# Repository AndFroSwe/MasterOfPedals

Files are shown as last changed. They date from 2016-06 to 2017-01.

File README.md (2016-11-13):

# Master of Pedals
A guitar pedal switching rig. Readymade presets are chosen by hitting a
footswitch on the stage pedal. The final goal of the repo is to have a modular
design that can easily be modified to the given specs.

# Features

1. At the hit of a footswitch, pedals are engaged as per the corresponding
   preset. No more tapdancing!
2. Presets can be changed on the main unit.

# Units

- __Control unit__: The main control unit. All pedals are connected to this and
presets are set here. 
- __Stage pedal__: Unit placed at the front of the stage. Has a set of
  footswitches for preset choice and a simple interface that shows the user
which preset is currently chosen.

# Repository guide

- __./Software/__ contains all source code for the MCUs. Divided into subfolders
  corresponding to the stage pedal and the control unit.
- __./KiCad/__ contains electrical schematics. Divided into subfolders
  corresponding to the stage pedal and the control unit.

# Prototype unit
The repo has a fully ready-to-go (when it's done) unit. This unit has the
following specs:

- 8 pedals in the control loop.
- 3 independently controlled amp channels.
- 6 presets.
- Stage pedal is connected via cord (i.e. it is not wireless).
- It has a simple user interface at the control unit that allows the user to
  change the presets.

# Future features
- __MIDI control output__: An output that can send MIDI messages to pedals.
- __Wireless control__: The stage pedal can send control signals to the control
  unit wirelessly. This also enables multiple control units. This could be used
in a mini control unit that is carried on the guitar.
- __Internal pedal power supply__: The control unit contains a PSU that can feed
  the guitar pedals with power.
- __Battery power supply__: The stage pedal runs on battery.
- __Data logging__: The pedal remembers which presets have been used.

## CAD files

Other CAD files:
KiCad/Channel switch prototype/Channel_Sw_Prototype-F.SilkS.dxf

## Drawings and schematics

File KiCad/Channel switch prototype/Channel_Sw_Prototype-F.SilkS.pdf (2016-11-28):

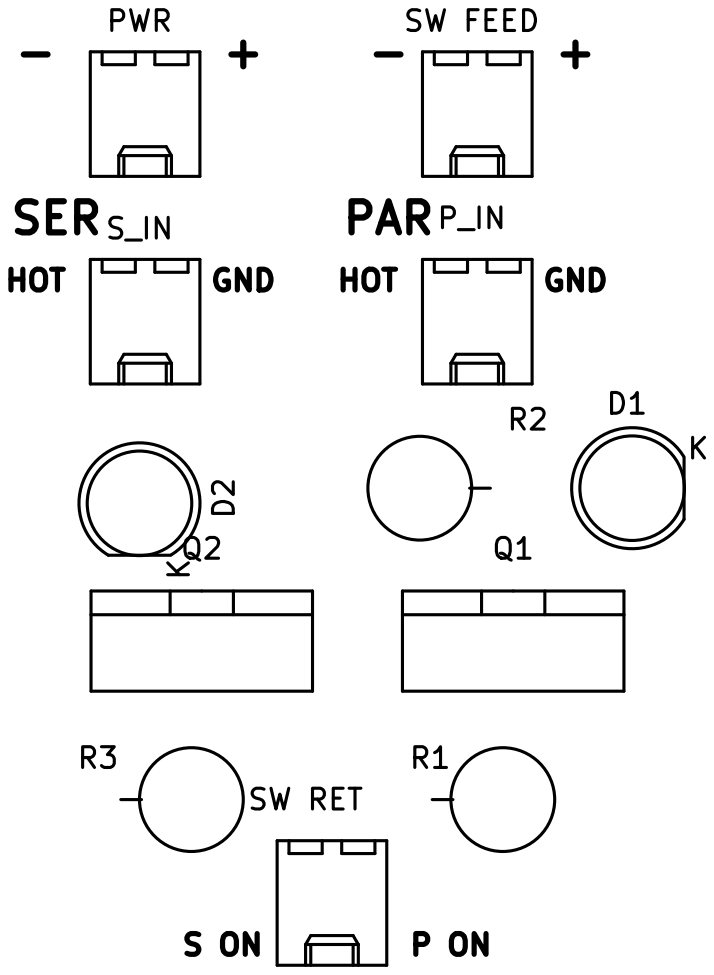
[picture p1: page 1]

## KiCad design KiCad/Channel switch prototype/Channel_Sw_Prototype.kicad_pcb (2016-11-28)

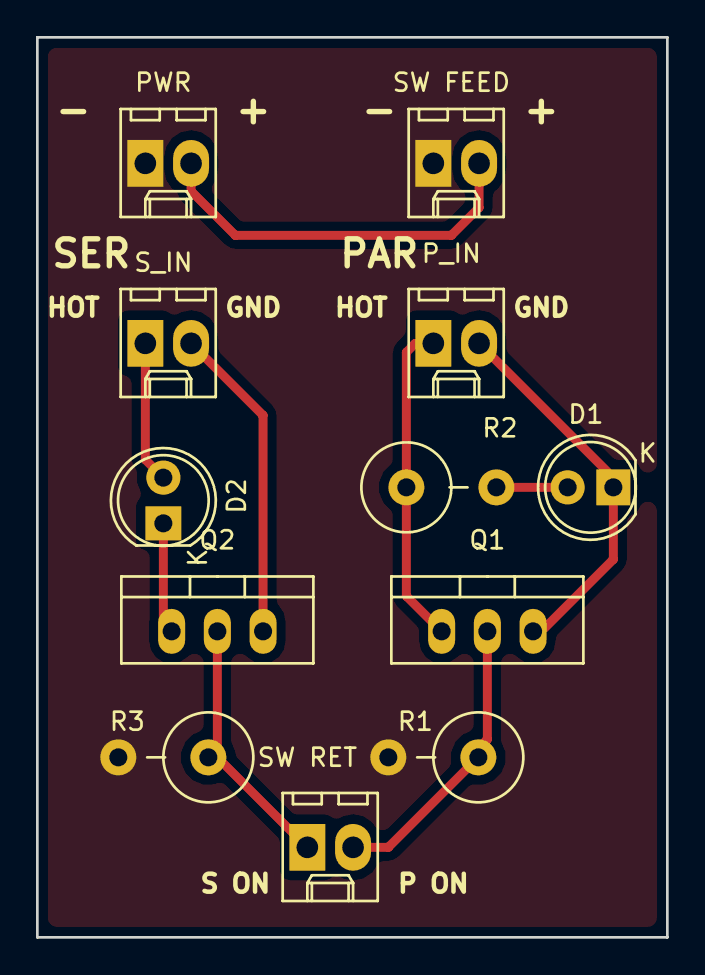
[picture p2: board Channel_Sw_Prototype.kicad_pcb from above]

Board: 2 copper layers, 35.0 x 50.0 mm, 12 parts (0 on the bottom side), 10 nets.

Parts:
D1, D2: LED; LED-5MM
PWR: PWR; Molex_KK-6410-02_02x2.54mm_Straight
P_IN: P IN; Molex_KK-6410-02_02x2.54mm_Straight
Q1, Q2: BUZ11; TO-220_Neutral123_Vertical
R1, R3: 1M; Resistor_Vertical_RM5mm
R2: 1.5k; Resistor_Vertical_RM5mm
SW FEED: SW FEED; Molex_KK-6410-02_02x2.54mm_Straight
SW RET: SW RETURN; Molex_KK-6410-02_02x2.54mm_Straight
S_IN: S IN; Molex_KK-6410-02_02x2.54mm_Straight

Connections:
/P_ON: Q1.2, R1.1, SW RET.2
/S_ON: Q2.2, R3.1, SW RET.1
/TELE_P_GND: D1.1, P_IN.2, Q1.3
/TELE_P_HOT: P_IN.1, Q1.1, R2.1
/TELE_S_GND: Q2.3, S_IN.2
/TELE_S_HOT: D2.2, S_IN.1
GND: PWR.1, R1.2, R3.2, SW FEED.1
unnamed: D1.2, R2.2
unnamed: D2.1, Q2.1
VCC: PWR.2, SW FEED.2

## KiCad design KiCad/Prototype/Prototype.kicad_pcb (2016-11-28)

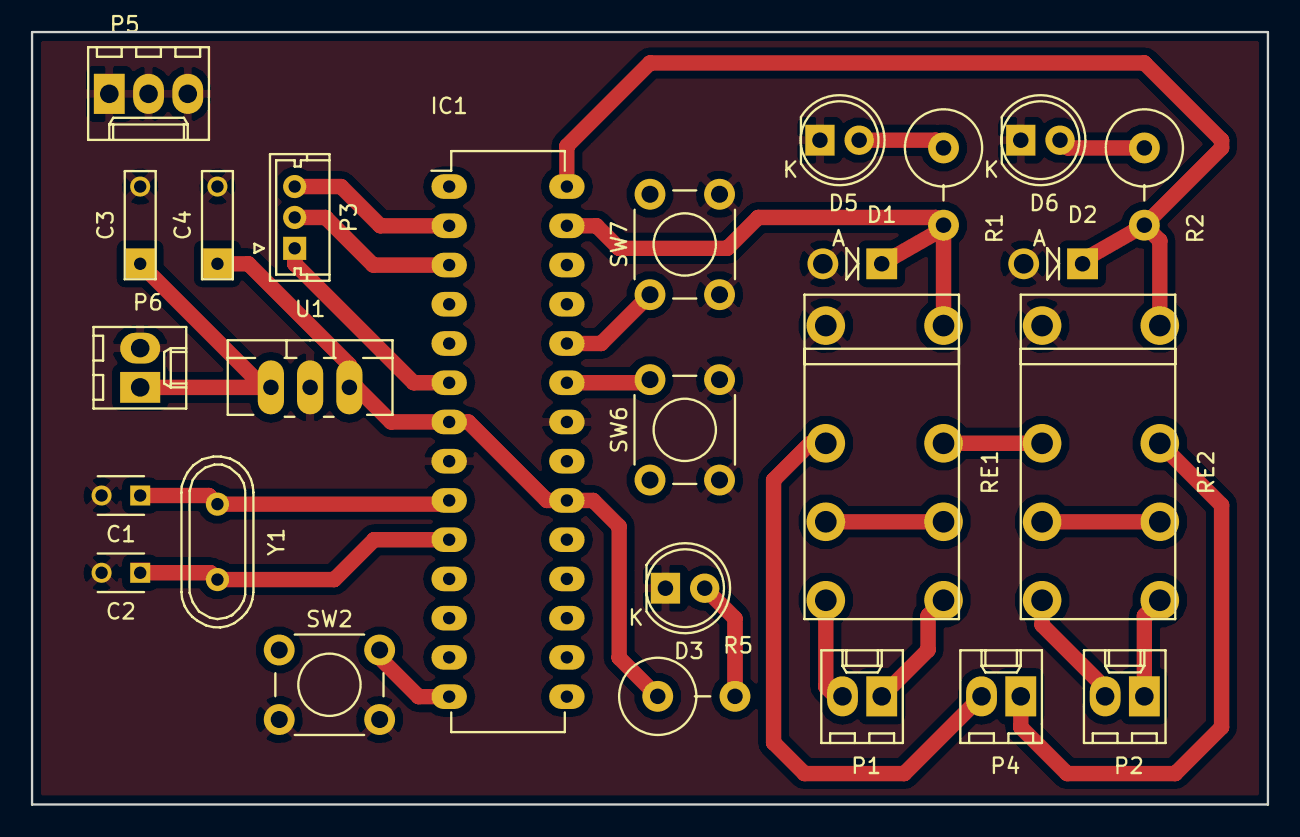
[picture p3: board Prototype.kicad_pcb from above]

Board: 2 copper layers, 80.0 x 50.0 mm, 26 parts (0 on the bottom side), 25 nets.

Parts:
C1, C2: 22pF; C_Disc_D3_P2.5
C3, C4: C; C_Rect_L7_W2_P5
D1, D2: D_Schottky; Diode_DO-41_SOD81_Vertical_AnodeUp
D3, D5, D6: LED; LED-5MM
IC1: ATMEGA328-P; DIP-28_W7.62mm_LongPads
P1, P2, P4, P6: CONN_01X02; Molex_KK-6410-02_02x2.54mm_Straight
P3: CONN_01X03; Molex_MicroLatch-53253-0370_03x2.00mm_Straight
P5: CONN_01X03; Molex_KK-6410-03_03x2.54mm_Straight
R1, R2, R5: R; Resistor_Vertical_RM5mm
RE1, RE2: DPDT-5V; DS2Y_PAK
SW2, SW6, SW7: SW_PUSH; SW_PUSH_6mm
U1: LM7805CT; TO-220_Neutral123_Vertical_LargePads
Y1: Crystal; Crystal_HC49-U_Vertical

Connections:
/G_IN: P4.2, RE1.7
/G_OUT: P4.1, RE2.2
/PED_1: D1.1, IC1.27, R1.2, RE1.1
/PED_2: D2.1, IC1.28, R2.2, RE2.1
/PRESET_1: IC1.14, SW2.1
/RX: IC1.2, P3.3
/SET_1: IC1.23, SW6.1
/SET_2: IC1.24, SW7.1
/TX: IC1.3, P3.2
/XCK: IC1.6, P3.1
/XTAL1: C1.1, IC1.9, Y1.1
/XTAL2: C2.1, IC1.10, Y1.2
GND: C1.2, C2.2, C3.2, C4.2, D1.2, D2.2, D3.1, D5.1, D6.1, IC1.8, IC1.22, P5.1, P5.2, P5.3, P6.2, RE1.8, RE2.8, SW2.2, SW6.2, SW7.2, U1.2
unnamed: D3.2, R5.2
unnamed: D5.2, R1.1
unnamed: D6.2, R2.1
unnamed: P1.1, RE1.4
unnamed: P1.2, RE1.5
unnamed: P2.1, RE2.4
unnamed: P2.2, RE2.5
unnamed: RE1.2, RE2.7
unnamed: RE1.3, RE1.6
unnamed: RE2.3, RE2.6
VCC: C3.1, P6.1, U1.1
VDD: C4.1, IC1.7, IC1.20, R5.1, U1.3

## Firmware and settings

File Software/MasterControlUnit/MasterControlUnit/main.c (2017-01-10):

/*
 * MasterControlUnit.c
 *
 * Created: 1/3/2017 5:01:10 PM
 * Author : Andreas Fröderberg
 */ 

#include "main.h"

/* Define states */
State s_run1 = {
	enc_green_on,
	enc_green_off
};

State s_run2 = {
	enc_red_on,
	enc_red_off
};

/* States and events */
State *states[] = {&s_run1,  &s_run2}; /* State array */
typedef enum State_code {run1, run2} State_code; /* State enumerators. Used for access */
typedef enum Event_code {enc_plus, enc_minus} Event_code; /* Available events */

typedef struct transitions { /* Standard transition format */
	State_code this_state;
	Event_code this_event;
	State_code next_state;
} Transitions;

Transitions transition_lookup[] = { /* Lookup table for all transitions */
	{run1, enc_plus, run2},
	{run1, enc_minus, run2},
	{run2, enc_plus, run1}
};

#define TRANS_COUNT (sizeof(transition_lookup)/sizeof(*transition_lookup)) /* Define number of transitions */

State_code cur_state = run1;

int main(void)
{
	enc_setup_pins();
	enc_setup_interrupts();
	states[cur_state]->entry_action();
    while (1) 
    {
    }
}



/** Interrupt service routines **/
ISR(ENC_INT_VECTOR) 
{
	/* 
	 * Interrupt service routine that handles encoder pulses.
	 */
	static int8_t lookup_table[] = {0, -1, 1, 0, 1, 0, 0, -1, -1, 0, 0, 1, 0, 1, -1, 0};
	static uint8_t enc_val = 0; /* Holds encoder history */
	static int8_t enc_count = 0; /* Holds amount of encoder ticks has passed since click */

	enc_val = enc_val << 2;    /* Make room for new readings */
	/* This part will need to be changed if encoder pins are changed */
	enc_val = enc_val | ((PIND & 0x0C) >> 2); /* Mask encoder pins and move them to LSB */
	enc_count += lookup_table[enc_val & 0x0F];  // update encoder history

	/* State machine handling */
	if ((enc_count/4) == 1) { /* Enc_plus event */
		make_transition(&cur_state, enc_plus);
		enc_count = 0;
	} else if ((enc_count/4) == -1) { /* Enc_minus event */
		make_transition(&cur_state, enc_minus);
		enc_count = 0;
	}
}
/*
ISR(TIMER0_COMPA_vect)
{
	debounced_read();
}
*/

/** State functions **/
inline void make_transition(State_code *s, Event_code e)
{
	/* 
	 * Fires appropriate entry and exit actions depending on current state
	 * and current event. Also updates current event global variable.
	 * Is inline to reduce function call overhead when run in an ISR.
	 * Not that NULL_EVENT should be defined to a number that is not 
	 * present in enum for states!
	 */
	State_code next_state = NULL_EVENT;
	lookup_transition(&next_state, *s, e);
	if (next_state != NULL_EVENT) {
		states[*s]->exit_action(); /* Before leaving current state */
		*s = next_state;
		states[*s]->entry_action(); /* Enter new state */
	}
}

inline void lookup_transition(State_code *next, State_code s, Event_code e)
{
	/* 
	 * Loops throuhg transition table and updates next state variable
	 * if there is a valid transition. Otherwise, next pointer is left
	 * as it was. This algorithm is to allow for events that should 
	 * trigger no action.
	 */
	int i; /* Loop variable */
	for(i = 0; i < TRANS_COUNT; ++i)
	{
		if ((s == transition_lookup[i].this_state) && (e == transition_lookup[i].this_event)) /* Find state and event in lookup */
		{
			*next = transition_lookup[i].next_state; /* Return the next state */
		}
	}
};

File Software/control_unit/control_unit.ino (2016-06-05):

#define PED1 8
#define PED2 9
#define PED3 10

int all_pedals[3] = {PED1, PED2, PED3};
int mode_1 = 0b111;
int mode_2 = 0b101;
int mode_3 = 0b100;
int all_modes[] = {mode_1, mode_2, mode_3};

int received;

void setup()
{
  // setup all pedal pins
  for (int i = 0; i < sizeof(all_pedals)/sizeof(int); i++)
  {
    pinMode(all_pedals[i], OUTPUT);
  }
  Serial.begin(9600);  // start serial
}

void loop()
{
  // check serial for messages
  if (Serial.available() > 0)
  {
    received = Serial.read();
    int received_as_int = received - '0'; // convert ascii to corresponding int
    if ((received_as_int >= 0) && (received_as_int < sizeof(all_pedals)/sizeof(int))) { // protect against non-valid inputs
      enable_pedals(received_as_int);
    }
  }
}

void kill_all() {
  for (int i = 0; i < sizeof(all_pedals)/sizeof(int); i++)
  {
    digitalWrite(all_pedals[i], LOW);
  }
}

void enable_pedals(int command) {
  /* starts all pedals according to mode */
  kill_all(); // start with killing all pedals
  // loop through mode variable and see which pedals to start
  int mode = all_modes[command];
  for (int i = 0; i < sizeof(all_pedals)/sizeof(int); i++)
  {
    if ((mode >> i) & 0x01) {
      digitalWrite(all_pedals[i], HIGH);
    }
  }
}

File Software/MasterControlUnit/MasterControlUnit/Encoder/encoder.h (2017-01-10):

/*
 * encoder.h
 *
 * Created: 1/5/2017 2:23:23 PM
 *  Author: Andreas Fröderberg
 */ 


#ifndef ENCODER_H_
#define ENCODER_H_

/*** Defines ***/
/* Encoder pins */
#define ENC_REGISTER DDRD /* Direction register of encoder pulses */
#define ENC_PORT PORTD /* Port register of encoder */
#define ENC_A_PIN PD2 /* Encoder A pulse */
#define ENC_B_PIN PD3 /* Encoder B pulse */
/* LED pins */
#define ENC_LED_REGISTER DDRB /* Direction register for encoder leds */
#define ENC_LED_PORT PORTB /* Port register for encoder leds */
#define ENC_GREEN PB6 /* Encoder green led pin */
#define ENC_RED PB7	/* Encoder red led pin */

/*** Includes ***/
#include <avr/io.h>
#include <avr/interrupt.h>
#include "../HSMlib/HSMlib.h"

/*** Prototypes ***/
void enc_setup_interrupts(void);
void enc_setup_pins(void);
void enc_green_on(void);
void enc_green_off(void);
void enc_red_on(void);
void enc_red_off(void);

#endif /* ENCODER_H_ */

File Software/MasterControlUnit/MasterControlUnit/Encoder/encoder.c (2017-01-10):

/*
 * encoder.c
 *
 * Created: 1/5/2017 2:23:34 PM
 *  Author: Andreas Fröderberg
 */ 

#include "encoder.h"

/** Setup functions **/
void enc_setup_interrupts(void)
{
	/* 
	* Setup pin interrupts for A and B pulse of encoder
	*/

	cli(); /* Disable interrupts */
	PCICR = _BV(PCIE2); /* Enable interrupts on PCINT 16:23 */
	PCMSK2 = _BV(ENC_A_PIN) | _BV(ENC_B_PIN); /* Mask desired pins */
	sei(); /* Enable interrupts */
}

void enc_setup_pins(void)
{
	/* 
	 * Set direction and initial state of pins needed for encoder
	 */

	 /* Encoder pulses */
	ENC_REGISTER &= ~_BV(ENC_A_PIN) & ~_BV(ENC_B_PIN); /* Encoder as inputs */
	ENC_PORT |= _BV(ENC_A_PIN) | _BV(ENC_B_PIN); /* Enable internal pullup resistors */
	/* Encoder leds */
	ENC_LED_REGISTER |= _BV(ENC_GREEN) | _BV(ENC_RED); /* Output for LEDS */
	/* Set leds to off */
	ENC_LED_PORT &= ~_BV(ENC_GREEN) & ~_BV(ENC_RED);
}


/* LED functions */
void enc_green_on(void)
{
	ENC_LED_PORT |= _BV(ENC_GREEN);
}

void enc_green_off(void)
{
	ENC_LED_PORT &= ~_BV(ENC_GREEN);
}

void enc_red_on(void)
{
	ENC_LED_PORT |= _BV(ENC_RED);
}

void enc_red_off(void)
{
	ENC_LED_PORT &= ~_BV(ENC_RED);
}

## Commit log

2016-06-04 Initial commit. first version of stage pedal added with prototype functions for interrupts on pedal press
2016-06-04 can now recognize which pin was triggered
2016-06-05 removed unnecessary prints
2016-09-30 Added TODOs and a couple of more informative parts to the readme
2016-11-01 Created pedal loop and started on amp switching loop
    [Amp switch.sch, ControlUnit.kicad_pcb, ControlUnit.sch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]
2016-11-16 Added a small prototype board to test with
    [Prototype.kicad_pcb, Prototype.sch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]
2016-11-18 Switched LM317 to 7805 and fixed pcb
    [Prototype.kicad_pcb, Prototype.sch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]
2016-11-28 Perfected prototype and added a guitar amp switch prototype
    [Channel_Sw_Prototype-F.SilkS.dxf, Channel_Sw_Prototype.kicad_pcb, Channel_Sw_Prototype.sch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]
2016-11-29 Added AVR project to prototype
    [_saved_Prototype.sch]
2016-12-17 Added software for the prototype and made a netlist with footprints for the control unit board
    [Amp switch.sch, ControlUnit.kicad_pcb, ControlUnit.sch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]
2017-01-04 Added a software project for the master control unit. Encoder reading works, there is button debounce also.
2017-01-12 Fine tuned PCB design and added multicontact connectors instead of single connectors
    [Amp switch.sch, ControlUnit.sch, PedalLoop.sch]
2017-01-27 Started making a program for prototype. Preset handling done
2017-01-27 Can now read button
2017-01-27 Prototype works, just needs some adjustments after box is done
